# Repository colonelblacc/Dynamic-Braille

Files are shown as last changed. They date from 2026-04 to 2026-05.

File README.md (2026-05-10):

# DynaBraille 🖐️

> **AI-powered reading desk for blind students** — scans physical textbook pages via camera, performs bilingual OCR (English + Malayalam), cleans text with a local Gemma LLM, speaks aloud through headphones, and renders each character on a custom-built dynamic Braille refresh cell driven by Arduino.

---

## 📸 Gallery

### Desk Setup & Hardware
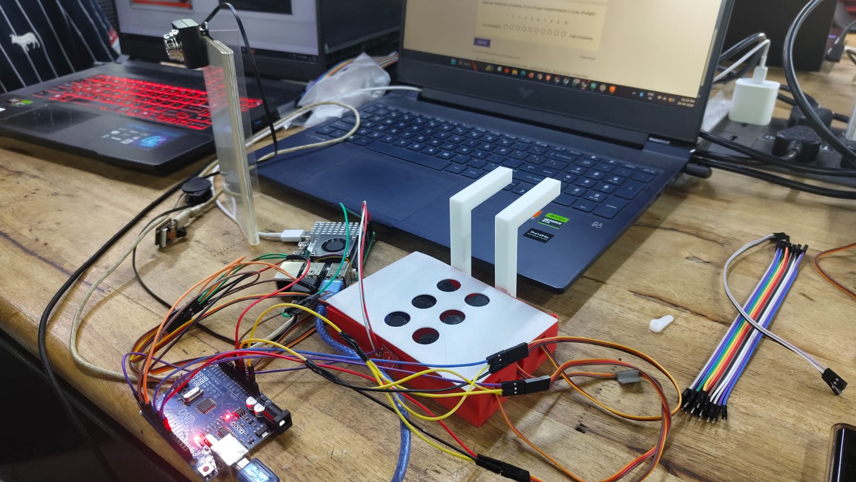
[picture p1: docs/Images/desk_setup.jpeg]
DynaBraille full desk setup


### Braille Cell Servo Assembly
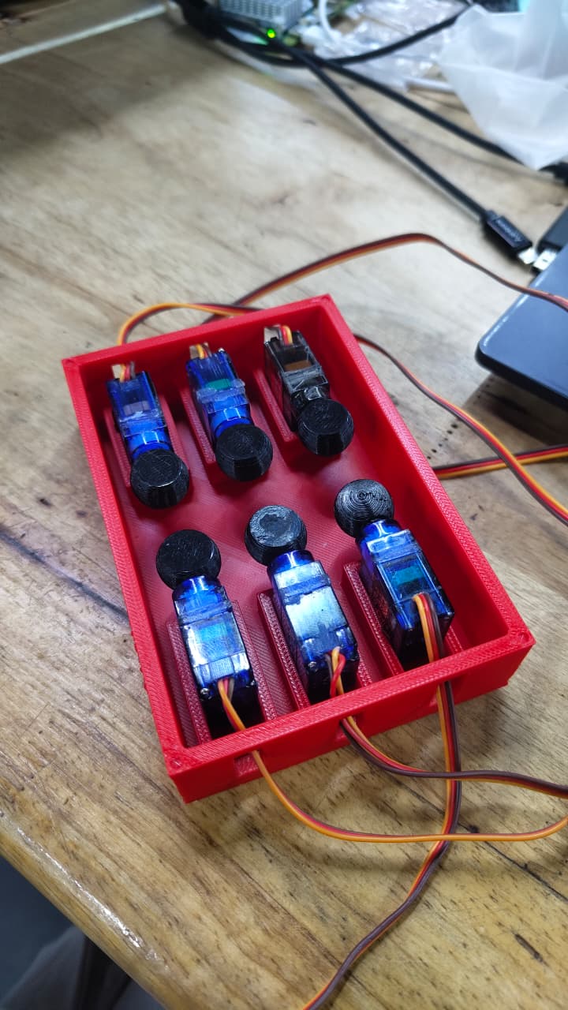
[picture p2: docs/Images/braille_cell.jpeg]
Braille cell - servo assembly


### Full System Working Flow

Watch: DynaBraille Full System Demo (https://youtube.com/shorts/Nej_g_eKN2o)

> 📺 Click the thumbnail above to watch the full system working demo on YouTube.

### Dynamic Braille Cell Loading Alphabets

Watch: Braille Cell Loading Alphabets (https://youtube.com/shorts/mgscIVhc7ok)

> 📺 Click the thumbnail above to watch the Braille cell cycle through alphabets on YouTube.

---

## How It Works

A blind student places their textbook under the camera and says **"scan"** (or presses a button). Within seconds, DynaBraille:

1. **Captures** the sharpest frame from the Pi Camera
2. **Detects** the page boundary and corrects perspective distortion
3. **Deskews** and enhances the image for OCR
4. **Runs bilingual OCR** — PaddleOCR for English, Tesseract for Malayalam — selecting the winner by confidence score
5. **Cleans** the raw OCR output using a local Gemma 2B LLM (via Ollama)
6. **Speaks** the result aloud through headphones using TTS
7. **Streams** the text to a custom Braille cell — one character at a time — via Arduino over UART serial

---

## Hardware

| Component | Details | Role |
|---|---|---|
| **Raspberry Pi 5** | Main compute board | Runs all AI, OCR, TTS, voice recognition |
| **Pi Camera 3** | 2304×1296 resolution | Page capture |
| **Headphones (TRRS)** | Mic + speaker in one | Voice command input + TTS audio output |
| **Arduino Uno** | ATmega328P | Receives text over UART, drives servos |
| **6× Micro Servo (SG90)** | 2×3 grid arrangement | Each servo raises/lowers one Braille dot pin |
| **3D-printed cell housing** | Custom red PLA enclosure | Holds servos in standard Braille 2×3 dot pattern |
| **Push buttons** | GPIO connected | Physical control (scan, read, next word, etc.) |
| **Touch sensor** | Mounted on the side of the Braille cell | Thumb-press to advance to the next word while fingers stay on the dots |

### Braille Cell Design

The Braille cell uses **6 SG90 micro servo motors** arranged in the standard Grade-1 Braille pattern (2 columns × 3 rows). Each servo arm has a Braille dot pin attached — rotating the servo arm raises or lowers the pin through the top plate, forming any Braille character.

The Raspberry Pi 5 sends characters over UART to the Arduino Uno, which interprets a `BRAILLE:xxxxxx\n` packet (6-bit pattern, one `0`/`1` per dot) and positions each servo accordingly.

```
Dot layout:        Packet format:
  1  4             BRAILLE:100100\n
  2  5                     ^^^^^^
  3  6                     dots 1-6
```

### Touch Sensor — Next Word Advance

A **touch sensor is mounted on the side of the Braille cell housing**. While the student's fingers rest on the Braille dots to read, they press the sensor with their thumb on the side to advance to the next word. The Arduino detects the touch and sends a `NEXT` signal to the Pi over UART, which loads and renders the next word on the cell. The student's hands **never leave the device** while reading.

---

## Software Architecture

```
Voice / Button input
        │
        ▼
  Intent Parser (rule-based → Gemma fallback)
        │
        ├── SCAN ──────────────────────────────────────────────┐
        │        Pi Camera captures sharpest of 3 frames       │
        │        → Perspective warp (page detection)           │
        │        → Deskew (skew angle correction)              │
        │        → CLAHE contrast enhance + denoise            │
        │        → PaddleOCR (English) — real confidence score │
        │             ≥ 0.80  → accept English                 │
        │             0.60–0.80 → run both, pick winner        │
        │             < 0.60  → Tesseract Malayalam            │
        │        → Gemma 2B cleans OCR noise (local, offline)  │
        │        → Page number extracted from bottom strip     │
        │                                                       │
        ├── READ / NEXT_WORD / NEXT_LINE                        │
        │        Speaks buffered text via pyttsx3 TTS ◄────────┘
        │        Streams to Braille cell via serial UART
        │        ← also triggered by touch sensor tap on cell
        │
        ├── EXPLAIN / SUMMARY / DESCRIBE
        │        Gemini 1.5 Flash (cloud) — explains / summarizes
        │        page text or describes diagrams in the camera frame
        │
        └── GO_TO_PAGE
                 Navigation guidance (pages forward/backward)
```

### Module map

| Module | File | What it does |
|---|---|---|
| Entry point | `main.py` | `BrailleDesk` class, intent dispatch, voice loop |
| Config | `config.py` | All tuneable parameters |
| OCR | `modules/ocr.py` | Bilingual pipeline (PaddleOCR + Tesseract) |
| Camera | `modules/camera.py` | picamera2 wrapper, sharpest-frame capture |
| Gemma | `modules/gemma.py` | OCR cleanup, Braille compression, intent fallback |
| Gemini | `modules/gemini.py` | Explain, summarize, Q&A, image description |
| TTS | `modules/tts.py` | pyttsx3 speech output |
| Voice | `modules/voice.py` | SpeechRecognition → Google ASR → Vosk fallback |
| Braille | `modules/braille.py` | Text → Grade-1 cells → Arduino serial |
| Buttons | `modules/buttons.py` | RPi.GPIO physical button handler |
| Arduino | `arduino/` | Servo control sketch (receives UART packets) |

---

## 🛠️ Replicating & Extending the Hardware

If you want to build your own DynaBraille unit, the most custom part is the Braille cell.

### 1. Build the Braille Cell
- **3D Print the Housing:** The housing needs 6 slots fitted for SG90 micro servos in a 2x3 grid. The top plate must have 6 corresponding holes for the Braille pins.
- **Servos & Pins:** Attach a small pin or lever to each servo horn. When the servo actuates, the pin should protrude through the top plate.
- **Touch Sensor:** Mount a capacitive touch sensor on the side of the housing where the user's thumb naturally rests.

### 2. Wire the Arduino
- Connect the 6 servo signal wires to the PWM pins on the Arduino Uno.
- Connect the side touch sensor to a digital input pin.
- Supply adequate power (5V) to the servos; do not power all 6 servos directly from the Arduino's 5V pin, as they may draw too much current. Use an external 5V power supply.

### 3. Test the Assembly
Once the Arduino is wired and the sketch is flashed, you can test the Braille cell independently without running the full AI pipeline:
```bash
# Smoke test: cycles through 'HELLO', 'abc123', and all-down
python tests/test_arduino.py

# Test a single dot (e.g., dot 1)
python tests/test_arduino.py --single 1
```

---

## Setup

### 1. System dependencies

```bash
# Tesseract OCR engine + Malayalam language pack
sudo apt install tesseract-ocr tesseract-ocr-mal

# espeak for TTS
sudo apt install espeak

# Audio (for headphone mic input)
sudo apt install portaudio19-dev
```

### 2. Python dependencies

```bash
pip install -r requirements.txt
```

> **PaddleOCR note:** `paddlepaddle` and `paddleocr` are CPU builds by default.
> Set `PADDLE_USE_GPU = True` in `config.py` if you have a CUDA-capable device.

### 3. Ollama + Gemma (local LLM)

```bash
# Install Ollama
curl -fsSL https://ollama.com/install.sh | sh

# Pull Gemma 2B (fits comfortably on Pi 5 with 8GB RAM)
ollama pull gemma2:2b

# For 4GB Pi, use the smaller variant:
# ollama pull gemma3:1b
# and update GEMMA_MODEL in config.py
```

### 4. Gemini API key (optional — cloud features only)

```bash
export GEMINI_API_KEY="your_key_here"
```

> Without this key, explain/summary/image-description features are disabled.
> Core scan, read, and Braille output work fully offline.

### 5. Arduino sketch

Flash the sketch in `arduino/` to the Uno using Arduino IDE.
Connect the Uno to the Pi 5 via USB. Verify the port in `config.py`:

```python
SERIAL_PORT = "/dev/ttyACM0"   # Uno → ttyACM0 | Nano → ttyUSB0
```

---

## Running

```bash
python main.py
```

### CLI flags

| Flag | Effect |
|---|---|
| `--no-braille` | Skip Arduino / Braille cell output |
| `--no-gemma` | Skip local Gemma OCR cleanup |
| `--no-gemini` | Skip cloud Gemini features |
| `--no-voice` | Keyboard input only (no microphone) |

**Fully offline / edge mode:**
```bash
python main.py --no-gemini
```

---

## Voice Commands

| Say | Action |
|---|---|
| `scan` | Capture and OCR the current page |
| `read` | Read the full page aloud |
| `next word` | Speak + Braille the next word |
| `next line` | Speak + Braille the next line |
| `repeat` | Repeat the last spoken text |
| `explain` | Gemini explains the page in simple language |
| `summarize` | Gemini summarizes the page in 3 sentences |
| `spell` | Spell the current word letter by letter |
| `braille` | Send first 40 characters to the Braille cell |
| `go to page 42` | Navigation guidance to page 42 |
| `stop` | Stop current output |

All commands also have matching **physical push buttons** (configurable GPIO pins in `config.py`).

---

## Configuration

All parameters live in `config.py`:

```python
# Camera
CAMERA_RESOLUTION = (2304, 1296)   # Pi Camera 3 native

# Bilingual OCR engine switching
PADDLE_ENABLED     = True          # False → Tesseract English only (lighter)
MALAYALAM_ENABLED  = True          # False → English only
OCR_HIGH_CONF      = 0.80          # Above this → accept PaddleOCR directly
OCR_LOW_CONF       = 0.60          # Below this → switch to Malayalam Tesseract
TESSDATA_DIR       = ""            # Path to local tessdata/ folder

# Local AI
OLLAMA_URL         = "http://localhost:11434"
GEMMA_MODEL        = "gemma2:2b"   # "gemma3:1b" for 4GB Pi

# Cloud AI
GEMINI_API_KEY     = ""            # Set via env var GEMINI_API_KEY
GEMINI_MODEL       = "gemini-1.5-flash"

# Braille cell timing
BRAILLE_SETTLE_MS  = 400           # Servo settle time between cells
SERIAL_PORT        = "/dev/ttyACM0"
SERIAL_BAUD        = 9600
```

---

## Project Structure

```
DynaBraille/
├── main.py              # Application entry point (BrailleDesk class)
├── config.py            # All configuration parameters
├── requirements.txt     # Python dependencies
├── setup.sh             # One-shot setup script
├── arduino/             # Arduino servo-driver sketch
├── modules/
│   ├── ocr.py           # Bilingual OCR pipeline (PaddleOCR + Tesseract)
│   ├── camera.py        # Pi Camera 3 / USB camera wrapper
│   ├── gemma.py         # Local Gemma LLM (OCR cleanup, intent parsing)
│   ├── gemini.py        # Cloud Gemini AI (explain, summarize, vision)
│   ├── braille.py       # Text → Grade-1 Braille → Arduino UART
│   ├── tts.py           # Text-to-speech (pyttsx3 / espeak)
│   ├── voice.py         # Voice recognition (Google ASR + Vosk fallback)
│   └── buttons.py       # Physical GPIO button handler
└── tests/               # Unit tests
```

---

## Offline / Edge Capability

| Feature | Online? | Offline? |
|---|---|---|
| OCR (English + Malayalam) | ✅ | ✅ |
| Gemma OCR cleanup | ✅ | ✅ (Ollama runs locally) |
| TTS speech output | ✅ | ✅ (espeak, no internet) |
| Braille cell output | ✅ | ✅ |
| Voice recognition | ✅ | ⚠️ Vosk needed (see config) |
| Gemini explain/summarize | ✅ | ❌ (cloud API) |

Run with `--no-gemini` for a fully air-gapped deployment.

---

## License

MIT

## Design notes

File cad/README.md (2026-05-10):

# CAD Files

This folder contains all mechanical and hardware design files for the **DynaBraille** project.

## Folder Structure (suggested)

```
cad/
├── enclosure/        # 3D-printable enclosure parts
├── pcb/              # PCB layouts and schematics
├── assembly/         # Full assembly files
└── exports/          # Exported formats (STL, DXF, STEP, Gerber)
```

## Supported File Types

| Format | Tool | Purpose |
|---|---|---|
| `.f3d` | Autodesk Fusion 360 | Native editable design files |
| `.step` / `.stp` | Any CAD tool | Universal exchange format |
| `.stl` | Slicer (e.g. Cura) | 3D printing |
| `.dxf` | Any CAD / laser cutter | 2D profiles |
| `.kicad_pcb` | KiCad | PCB layout |
| `.sch` | KiCad / EasyEDA | Schematic |
| `.gerber` / `.gbr` | PCB manufacturers | Fabrication files |

## How to Contribute

1. Place your files in the appropriate subfolder above.
2. Use descriptive names — e.g., `top_cover_v2.stl` instead of `file1.stl`.
3. If you update an existing part, increment the version suffix (`_v2`, `_v3`).
4. For large binary files, consider using **Git LFS** (see below).

## Git LFS (Large File Storage)

CAD files can be large. If you have Git LFS installed, it is already configured
to track common CAD formats in this repo (see `.gitattributes`).

To install Git LFS:
```bash
# Ubuntu / Debian
sudo apt install git-lfs
git lfs install

# macOS
brew install git-lfs
git lfs install
```

## Contact

For questions about the hardware design, reach out to the hardware team lead.

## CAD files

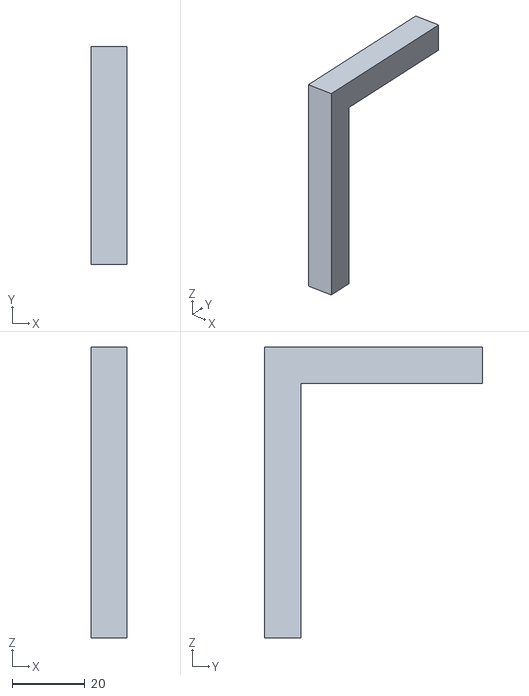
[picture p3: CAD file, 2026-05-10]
cad/Base.stl
10.0 x 60.0 x 80.0

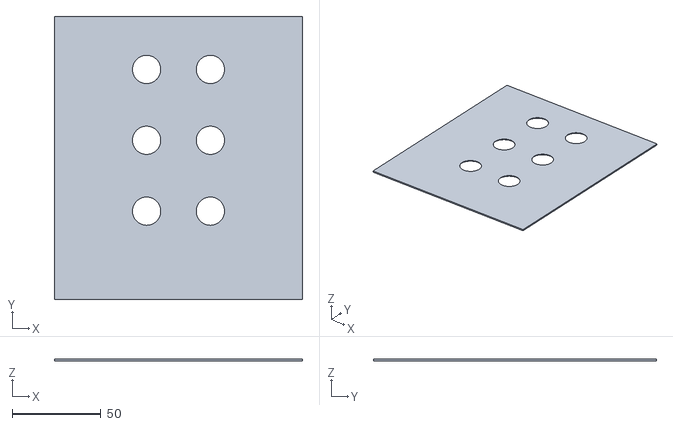
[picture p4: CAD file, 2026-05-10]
cad/platform.stl
140.0 x 160.0 x 1.00

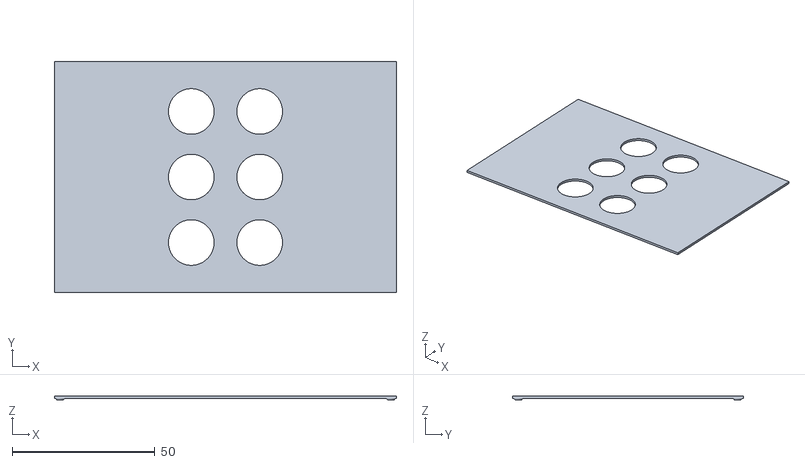
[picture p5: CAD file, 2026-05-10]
cad/Platform braille.stl
120.0 x 81.0 x 1.55

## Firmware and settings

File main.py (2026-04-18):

"""
DynaBraille — AI-assisted multimodal reading desk for blind students.

Pipeline:
    Voice command / button press
        → intent parsing (rule-based, Gemma fallback)
        → camera capture + OCR
        → Gemma text cleanup / simplification
        → Gemini explanation / Q&A / navigation guidance
        → TTS spoken response
        → Braille cell output

Run:
    python main.py [--no-braille] [--no-gemma] [--no-gemini] [--no-voice]
"""
import argparse
import logging
import re
import textwrap
import threading
from typing import List, Optional

import config
from modules.camera import Camera
from modules.ocr import process_frame, OcrResult
from modules.gemma import GemmaClient
from modules.gemini import GeminiClient
from modules.tts import TTSEngine
from modules.voice import VoiceListener
from modules.braille import BrailleController
from modules.buttons import ButtonHandler


def _setup_logging():
    logging.basicConfig(
        level=getattr(logging, config.LOG_LEVEL, logging.INFO),
        format="%(asctime)s %(name)s %(levelname)s: %(message)s",
    )


# ---------------------------------------------------------------------------
# Intent parser — rule-based first, Gemma fallback
# ---------------------------------------------------------------------------

_GO_RE  = re.compile(r"(?:go to|open|turn to|find|page)\s+page\s*(\d+)", re.I)
_PAGE_RE = re.compile(r"\bpage\s*(\d+)\b", re.I)

def parse_intent(utterance: str, gemma: Optional[GemmaClient] = None) -> dict:
    t = utterance.lower().strip()

    m = _GO_RE.search(t) or _PAGE_RE.search(t) if "page" in t else None
    if m:
        return {"intent": "GO_TO_PAGE", "args": {"page": int(m.group(1))}}

    if any(w in t for w in ("scan", "capture", "take a photo", "photograph")):
        return {"intent": "SCAN", "args": {}}
    if re.search(r"\bread\b", t):
        return {"intent": "READ", "args": {}}
    if any(w in t for w in ("explain", "what does", "what is", "simplify",
                             "tell me about", "describe")):
        return {"intent": "EXPLAIN", "args": {}}
    if re.search(r"\bspell\b", t):
        return {"intent": "SPELL", "args": {}}
    if "next word" in t:
        return {"intent": "NEXT_WORD", "args": {}}
    if "next line" in t or "next sentence" in t:
        return {"intent": "NEXT_LINE", "args": {}}
    if "next" in t:
        return {"intent": "NEXT_WORD", "args": {}}
    if any(w in t for w in ("repeat", "say again", "again")):
        return {"intent": "REPEAT", "args": {}}
    if "braille" in t:
        return {"intent": "BRAILLE", "args": {}}
    if "summar" in t:
        return {"intent": "SUMMARY", "args": {}}
    if any(w in t for w in ("stop", "pause", "quiet", "silence")):
        return {"intent": "STOP", "args": {}}

    # Ask Gemma only if nothing matched locally
    if gemma:
        return gemma.parse_intent(utterance)
    return {"intent": "UNKNOWN", "args": {}}


# ---------------------------------------------------------------------------
# BrailleDesk — main application class
# ---------------------------------------------------------------------------

class BrailleDesk:
    def __init__(self, args):
        self.log = logging.getLogger("BrailleDesk")
        self._lock = threading.Lock()

        # Session state
        self.current_page: Optional[int] = None
        self.current_text: str = ""
        self.current_frame = None
        self.last_spoken: str = ""
        self._words: List[str] = []
        self._lines: List[str] = []
        self._word_idx: int = 0
        self._line_idx: int = 0

        # Hardware / AI modules (all optional with graceful degradation)
        self.cam = Camera()
        self.cam.start()

        self.tts = TTSEngine()

        self.gemma: Optional[GemmaClient] = None
        if not args.no_gemma:
            g = GemmaClient()
            if g.is_available():
                self.gemma = g
            else:
                self.log.warning("Gemma/Ollama not reachable; OCR cleanup disabled.")

        self.gemini: Optional[GeminiClient] = None
        if not args.no_gemini:
            g2 = GeminiClient()
            if g2.is_available():
                self.gemini = g2
            else:
                self.log.warning("Gemini not available; advanced AI disabled.")

        self.braille: Optional[BrailleController] = None
        if not args.no_braille:
            try:
                bc = BrailleController()
                bc.connect()
                self.braille = bc
            except Exception as e:
                self.log.warning("Braille controller unavailable (%s).", e)

        self.voice: Optional[VoiceListener] = None
        if not args.no_voice:
            vl = VoiceListener()
            if vl.is_available():
                self.voice = vl
            else:
                self.log.warning("Voice input unavailable; keyboard fallback active.")

        self.buttons = ButtonHandler()
        self._register_buttons()

    # -----------------------------------------------------------------------
    # Button wiring
    # -----------------------------------------------------------------------

    def _register_buttons(self):
        mapping = {
            "SCAN":      self.do_scan,
            "READ":      self.do_read,
            "NEXT_WORD": self.do_next_word,
            "NEXT_LINE": self.do_next_line,
            "REPEAT":    self.do_repeat,
            "BRAILLE":   self.do_braille_mode,
            "EXPLAIN":   self.do_explain,
            "STOP":      self.do_stop,
        }
        for action, cb in mapping.items():
            self.buttons.register(action, cb)

    # -----------------------------------------------------------------------
    # Core actions
    # -----------------------------------------------------------------------

    def do_scan(self):
        """Capture frame, run OCR, clean with Gemma, update session state."""
        self.say("Scanning the page...")
        frame = self.cam.capture_sharpest(n=3)
        self.cam.save(frame)
        self.current_frame = frame

        result: OcrResult = process_frame(frame)
        raw = result.text

        cleaned = raw
        if self.gemma and raw.strip():
            cleaned = self.gemma.clean_ocr(raw)

        self.current_text = cleaned.strip()
        self.current_page = result.page_number
        self._words = self.current_text.split()
        self._lines = [l.strip() for l in self.current_text.splitlines() if l.strip()]
        self._word_idx = 0
        self._line_idx = 0

        if result.page_number:
            self.say(f"Scanned page {result.page_number}.")
        else:
            self.say("Page scanned. Page number not detected.")

        if not self.current_text:
            self.say("No readable text found on this page.")
            return

        # Preview: read first line aloud
        preview = self._lines[0][:120] if self._lines else ""
        if preview:
            self.say(preview)

    def do_read(self):
        """Read the full page text aloud."""
        if not self.current_text:
            self.say("Nothing scanned yet. Please scan a page first.")
            return
        self.say("Reading the page.")
        chunk = textwrap.fill(self.current_text[:800], width=200)
        self.say(chunk)

    def do_next_word(self):
        """Speak and Braille the next word in the text."""
        if not self._words:
            self.say("Please scan a page first.")
            return
        if self._word_idx >= len(self._words):
            self.say("End of page.")
            self._word_idx = 0
            return
        word = self._words[self._word_idx]
        self._word_idx += 1
        self.say(word)
        self._braille_send(word + " ")

    def do_next_line(self):
        """Speak and Braille the next line."""
        if not self._lines:
            self.say("Please scan a page first.")
            return
        if self._line_idx >= len(self._lines):
            self.say("End of page.")
            self._line_idx = 0
            return
        line = self._lines[self._line_idx]
        self._line_idx += 1
        self.say(line)
        self._braille_send(line[:40])

    def do_repeat(self):
        """Repeat the last spoken text."""
        if self.last_spoken:
            self.say(self.last_spoken, record=False)
        else:
            self.say("Nothing to repeat yet.")

    def do_explain(self):
        """Use Gemini to explain the current page in simple language."""
        if not self.current_text:
            self.say("Nothing scanned yet. Please scan a page first.")
            return
        if not self.gemini:
            self.say("Explanation requires an internet connection and Gemini API key.")
            return
        self.say("Let me explain that for you...")
        explanation = self.gemini.explain_text(self.current_text[:1500])
        if explanation:
            self.say(explanation)
        else:
            self.say("I could not generate an explanation right now.")

    def do_braille_mode(self):
        """Send the first 40 characters of current text to the Braille cell."""
        if not self.current_text:
            self.say("Nothing scanned yet.")
            return
        if not self.braille:
            self.say("Braille cell not connected.")
            return
        preview = self.current_text[:40]
        self.say(f"Sending to Braille: {preview}")
        self._braille_send(preview)

    def do_stop(self):
        self.say("Stopping.")

    def do_go_to_page(self, target: int):
        """Guide the user to find a specific page."""
        if self.gemini:
            msg = self.gemini.guide_navigation(self.current_page, target)
        else:
            if self.current_page is None:
                msg = f"Please scan a page first so I can tell where you are."
            elif self.current_page == target:
                msg = f"You are already on page {target}."
            else:
                diff = target - self.current_page
                direction = "forward" if diff > 0 else "backward"
                n = abs(diff)
                msg = (f"You are on page {self.current_page}. "
                       f"Turn {n} {'page' if n == 1 else 'pages'} "
                       f"{direction} to reach page {target}.")
        self.say(msg)

    def do_spell(self):
        """Spell out the current word letter by letter."""
        if not self._words:
            self.say("Please scan a page first.")
            return
        idx = max(0, self._word_idx - 1)
        word = self._words[idx]
        spelled = ", ".join(word.upper())
        self.say(f"{word}: {spelled}")
        self._braille_send(word)

    def do_summary(self):
        """Use Gemini to summarize the page."""
        if not self.current_text:
            self.say("Nothing scanned yet.")
            return
        if not self.gemini:
            self.say("Summary requires Gemini. Please set GEMINI_API_KEY.")
            return
        self.say("Summarizing the page...")
        summary = self.gemini.summarize_page(self.current_text[:2000])
        if summary:
            self.say(summary)
        else:
            self.say("Could not generate a summary right now.")

    # -----------------------------------------------------------------------
    # Command dispatch
    # -----------------------------------------------------------------------

    def handle_command(self, utterance: str):
        self.log.info("Command: %r", utterance)
        intent = parse_intent(utterance, self.gemma)
        name = intent.get("intent", "UNKNOWN")
        args = intent.get("args", {})

        dispatch = {
            "SCAN":       self.do_scan,
            "READ":       self.do_read,
            "NEXT_WORD":  self.do_next_word,
            "NEXT_LINE":  self.do_next_line,
            "REPEAT":     self.do_repeat,
            "EXPLAIN":    self.do_explain,
            "BRAILLE":    self.do_braille_mode,
            "SPELL":      self.do_spell,
            "SUMMARY":    self.do_summary,
            "STOP":       self.do_stop,
        }

        if name == "GO_TO_PAGE":
            self.do_go_to_page(args.get("page", 1))
        elif name in dispatch:
            dispatch[name]()
        else:
            self.say("I didn't understand that. Try saying: scan, read, explain, "
                     "next word, next line, repeat, or go to page number.")

    # -----------------------------------------------------------------------
    # Helpers
    # -----------------------------------------------------------------------

    def say(self, text: str, record: bool = True):
        if record:
            self.last_spoken = text
        self.tts.speak(text)

    def _braille_send(self, text: str):
        if self.braille:
            threading.Thread(
                target=self.braille.send_text,
                args=(text,),
                kwargs={"per_cell_delay_ms": 900},
                daemon=True,
            ).start()

    def shutdown(self):
        self.cam.stop()
        if self.braille:
            self.braille.close()
        if self.voice:
            self.voice.stop()
        self.buttons.cleanup()
        self.log.info("Shutdown complete.")


# ---------------------------------------------------------------------------
# Entry point — voice loop or keyboard fallback
# ---------------------------------------------------------------------------

def run(args):
    _setup_logging()
    log = logging.getLogger("main")

    desk = BrailleDesk(args)
    desk.say(
        "DynaBraille is ready. "
        "Say a command like: scan, read, explain, next word, or go to page 85."
    )

    try:
        if desk.voice and not args.no_voice:
            log.info("Starting continuous voice listening...")
            desk.say("Voice mode active. Listening for your commands.")
            desk.voice.start_continuous(desk.handle_command)

            # Keep main thread alive; voice runs in background thread
            while True:
                try:
                    cmd = input()           # still allows keyboard override
                    if cmd.strip():
                        desk.handle_command(cmd.strip())
                except EOFError:
                    import time; time.sleep(1)

        else:
            # Keyboard fallback — useful on a laptop or when no mic available
            desk.say("Keyboard mode. Type a command and press Enter.")
            while True:
                try:
                    cmd = input("\nCommand> ").strip()
                    if cmd:
                        desk.handle_command(cmd)
                except EOFError:
                    break

    except KeyboardInterrupt:
        print("\nShutting down...")
    finally:
        desk.shutdown()


if __name__ == "__main__":
    ap = argparse.ArgumentParser(description="DynaBraille reading desk")
    ap.add_argument("--no-braille", action="store_true",
                    help="Skip Arduino/Braille output")
    ap.add_argument("--no-gemma",   action="store_true",
                    help="Skip local Gemma OCR cleanup")
    ap.add_argument("--no-gemini",  action="store_true",
                    help="Skip Gemini cloud AI features")
    ap.add_argument("--no-voice",   action="store_true",
                    help="Keyboard input only (no microphone)")
    run(ap.parse_args())

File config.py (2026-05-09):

import os

# ---------- Camera ----------
CAMERA_RESOLUTION = (2304, 1296)   # Pi Camera 3 native; good for OCR
CAMERA_WARMUP_SEC = 1.0
CAPTURE_DIR = "/tmp/brailledesk"
os.makedirs(CAPTURE_DIR, exist_ok=True)

# ---------- OCR ----------
TESSERACT_LANG = "eng"
TESSERACT_PSM_BLOCK = 6            # uniform block of text
TESSERACT_PSM_SPARSE = 11          # sparse text (page numbers)
OCR_WARP_SIZE = (1600, 2200)
MIN_PAGE_AREA_RATIO = 0.25

# ---------- Bilingual OCR (PaddleOCR + Malayalam fallback) ----------
PADDLE_ENABLED = True              # set False to skip PaddleOCR (English-only, lighter)
PADDLE_USE_GPU = False             # set True if CUDA is available
MALAYALAM_ENABLED = True           # set False to disable Tesseract Malayalam fallback
TESSDATA_DIR = ""                  # path to tessdata dir; "" = system default
# Confidence thresholds for dynamic engine switching
OCR_HIGH_CONF = 0.80               # above this → accept PaddleOCR result directly
OCR_LOW_CONF  = 0.60               # below this → hard-switch to Malayalam Tesseract

# ---------- Gemma (Ollama — local) ----------
OLLAMA_URL = "http://localhost:11434"
GEMMA_MODEL = "gemma2:2b"          # use "gemma3:1b" on 4GB Pi
GEMMA_TIMEOUT = 30
GEMMA_TEMPERATURE = 0.2

# ---------- Gemini (cloud) ----------
GEMINI_API_KEY = os.getenv("GEMINI_API_KEY", "")
GEMINI_MODEL = "gemini-1.5-flash"  # fast + cheap; switch to "gemini-1.5-pro" for depth

# ---------- Arduino / Braille ----------
SERIAL_PORT = "/dev/ttyACM0"       # Uno: ttyACM0  |  Nano: ttyUSB0
SERIAL_BAUD = 9600
SERIAL_TIMEOUT = 2.0
BRAILLE_SETTLE_MS = 400

# ---------- TTS ----------
TTS_RATE = 150                     # words per minute (espeak default ~175)

# ---------- Voice / Microphone ----------
MIC_DEVICE_INDEX = None            # None = system default
MIC_ENERGY_THRESHOLD = 300        # SpeechRecognition energy gate
VOSK_MODEL_PATH = ""               # set to path of vosk model dir for offline ASR

# ---------- Physical Buttons (BCM pin numbers) ----------
# Map BCM GPIO pin -> action string.  Edit for your wiring.
BUTTON_PINS: dict = {
    17: "SCAN",
    27: "READ",
    22: "NEXT_WORD",
    23: "NEXT_LINE",
    24: "REPEAT",
    25: "BRAILLE",
    5:  "EXPLAIN",
    6:  "STOP",
}

# ---------- Logging ----------
LOG_LEVEL = "INFO"

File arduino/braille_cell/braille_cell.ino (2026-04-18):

/*
 * BrailleDesk - 6-dot rotating-ball Braille cell firmware
 * Target: Arduino Uno / Nano (ATmega328P)
 *
 * Serial protocol (9600 baud):
 *   Input:  "BRAILLE:xxxxxx\n"  where x is '0' (flat) or '1' (raised)
 *           Dots are numbered 1..6 in standard Braille order:
 *              1 4
 *              2 5
 *              3 6
 *   Output: "OK\n"  after servos have been commanded
 *           "ERR:<reason>\n" on a bad packet
 *
 * Power notes:
 *   - Do NOT power six servos from the Arduino 5V pin. Use a separate
 *     5-6V / 3A buck converter for the servo rail. Tie grounds together.
 *   - Add a 1000uF cap across the servo rail near the servos.
 */

#include <Servo.h>

// -------- Pin mapping (all PWM-capable on the Uno/Nano) --------
const uint8_t DOT_PINS[6] = {3, 5, 6, 9, 10, 11};

// -------- Servo end-angles --------
// Tune these per mechanism. FLAT is the flat face up, RAISED is the bumpy face up.
const uint8_t FLAT_ANGLE   = 10;
const uint8_t RAISED_ANGLE = 170;

Servo dots[6];
char currentState[7] = "000000";   // last commanded state (+ null)

void setAll(const char* bits) {
  for (uint8_t i = 0; i < 6; i++) {
    dots[i].write(bits[i] == '1' ? RAISED_ANGLE : FLAT_ANGLE);
  }
  memcpy(currentState, bits, 6);
  currentState[6] = '\0';
}

void setup() {
  Serial.begin(9600);
  for (uint8_t i = 0; i < 6; i++) {
    dots[i].attach(DOT_PINS[i]);
    dots[i].write(FLAT_ANGLE);
  }
  // Give servos time to reach home before accepting commands
  delay(500);
  Serial.println("READY");
}

void loop() {
  static char buf[32];
  static uint8_t idx = 0;

  while (Serial.available()) {
    char c = Serial.read();
    if (c == '\n' || c == '\r') {
      buf[idx] = '\0';
      handleLine(buf);
      idx = 0;
    } else if (idx < sizeof(buf) - 1) {
      buf[idx++] = c;
    } else {
      // overflow - reset
      idx = 0;
    }
  }
}

void handleLine(const char* line) {
  // Expect "BRAILLE:xxxxxx"
  const char* prefix = "BRAILLE:";
  const uint8_t pref_len = 8;
  if (strncmp(line, prefix, pref_len) != 0) {
    Serial.println("ERR:prefix");
    return;
  }
  const char* bits = line + pref_len;
  if (strlen(bits) < 6) {
    Serial.println("ERR:len");
    return;
  }
  for (uint8_t i = 0; i < 6; i++) {
    if (bits[i] != '0' && bits[i] != '1') {
      Serial.println("ERR:char");
      return;
    }
  }
  char clean[7];
  memcpy(clean, bits, 6);
  clean[6] = '\0';
  setAll(clean);
  Serial.println("OK");
}

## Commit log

2026-05-10 Create fusion360
    The Fusion 360 models included in this repository contain the mechanical architecture of the tactile display system, including:
    Braille cell housing
    Servo mounting structure
    Compact 3×2 Braille dot matrix assembly
    Frame and enclosure components
    Alignment and support structures for synchronized tactile output
2026-05-10 CAD files
2026-05-10 chore: add cad/ folder for hardware design files
